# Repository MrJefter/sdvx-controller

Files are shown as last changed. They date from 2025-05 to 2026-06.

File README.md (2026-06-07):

# DIY SDVX Controller

[Read this page in Russian (Читать на русском)](README_RU.md)

SDVX Controller Assembly Render

Hello! This is a DIY controller project for Sound Voltex and similar rhythm games. It's built using an STM32 microcontroller (Black Pill), with custom firmware, a custom PCB, and a 3D-printed enclosure.

## Project Features

*   **Microcontroller** STM32F401 (on a Black Pill v3.0 board).
*   **Buttons** 7 main (BT-A, B, C, D, START) + 2 FX buttons (FX-L, FX-R) on CherryMX switches (e.g., Outemu Red).
*   **Rotary encoders** 2 x LPD3806 (VOL-L, VOL-R).
*   **Addressable RGB lighting** on WS2812B LEDs (optional, strip connected to PB0).
*   **Interface** USB HID (the controller is recognized as a standard game device).
*   **Fully 3D-printed enclosure**.
*   **PCB** ideal for single-layer home etching, no need to order a board.

## Demonstration

MVP Link

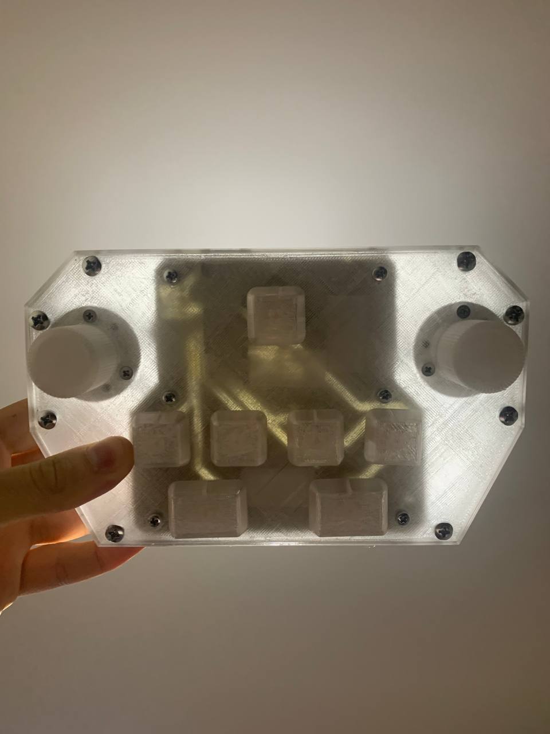
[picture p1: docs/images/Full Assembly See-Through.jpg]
Full Assembly See-Through


## Hardware

All hardware-related files are located in the [`hardware/`](./hardware/) folder.

### PCB

The PCB project was designed in EasyEDA. Source files, Gerber files for ordering, and the BOM are located in `hardware/pcb/`.

| Schematic | Board Layout |
|---|---|
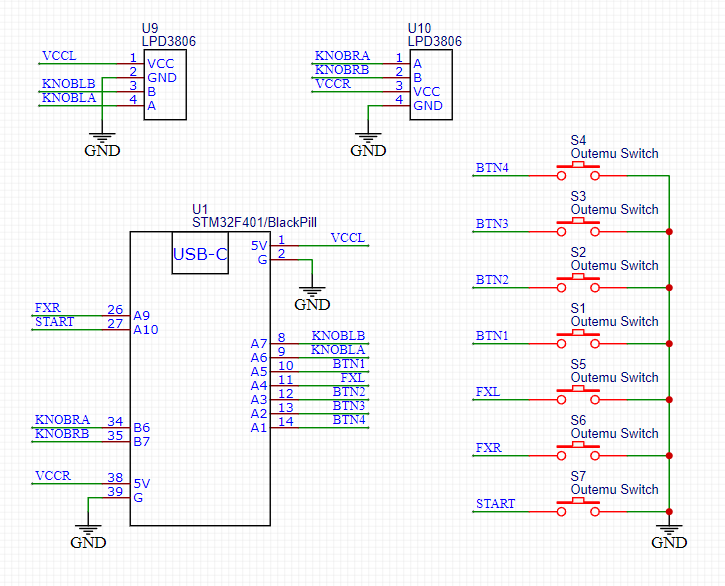
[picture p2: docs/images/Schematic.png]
Schematic
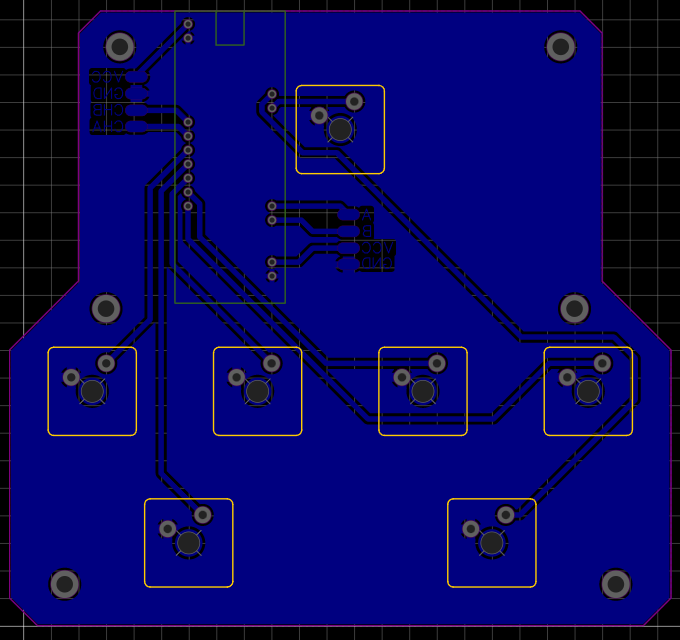
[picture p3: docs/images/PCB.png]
PCB Layout
|  |  |

**PCB Assembly Photos:**

| PCB Front | PCB Back |
|---|---|
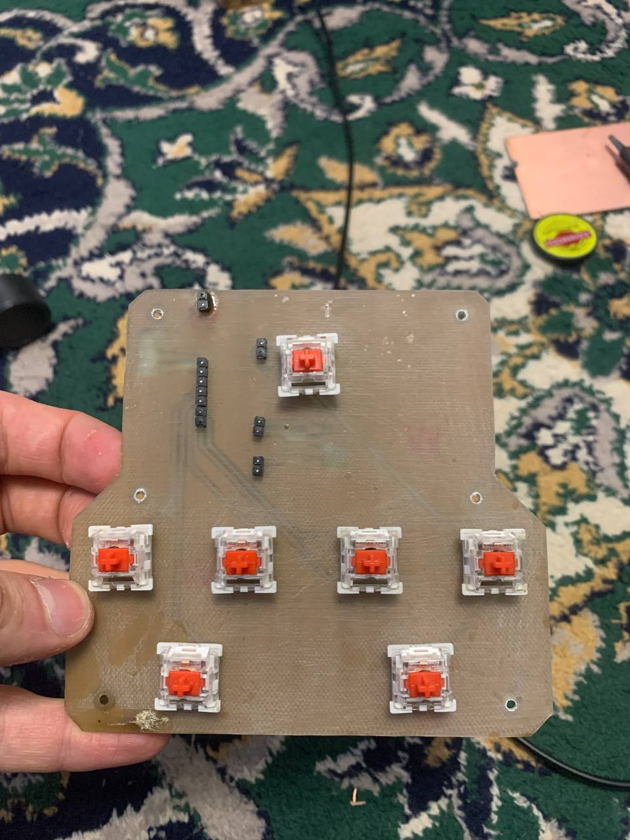
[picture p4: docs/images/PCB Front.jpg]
PCB Front
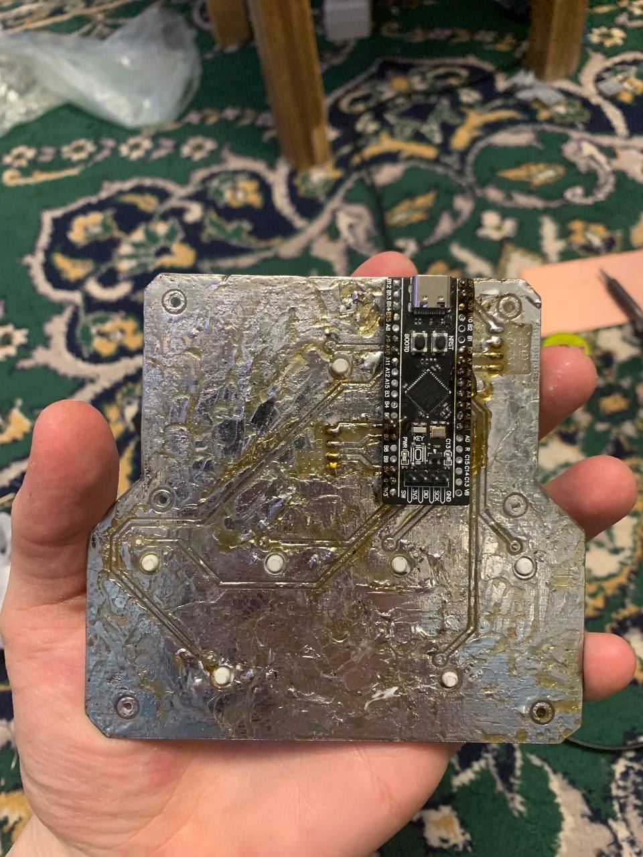
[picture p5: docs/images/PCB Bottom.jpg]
PCB Back
|  |  |

### Enclosure

3D models for the enclosure and its components were designed in KOMPAS-3D. Source CAD files, exported STEP files, and STL files for printing are located in `hardware/enclosure/` and `hardware/stl_for_printing/`.

3D models of the components used (BlackPill, encoders, switches) are in `hardware/enclosure/component_models_3d/`.

### Assembly Process (Photos)

| Connecting encoders to the front panel | LED strip installation |
|---|---|
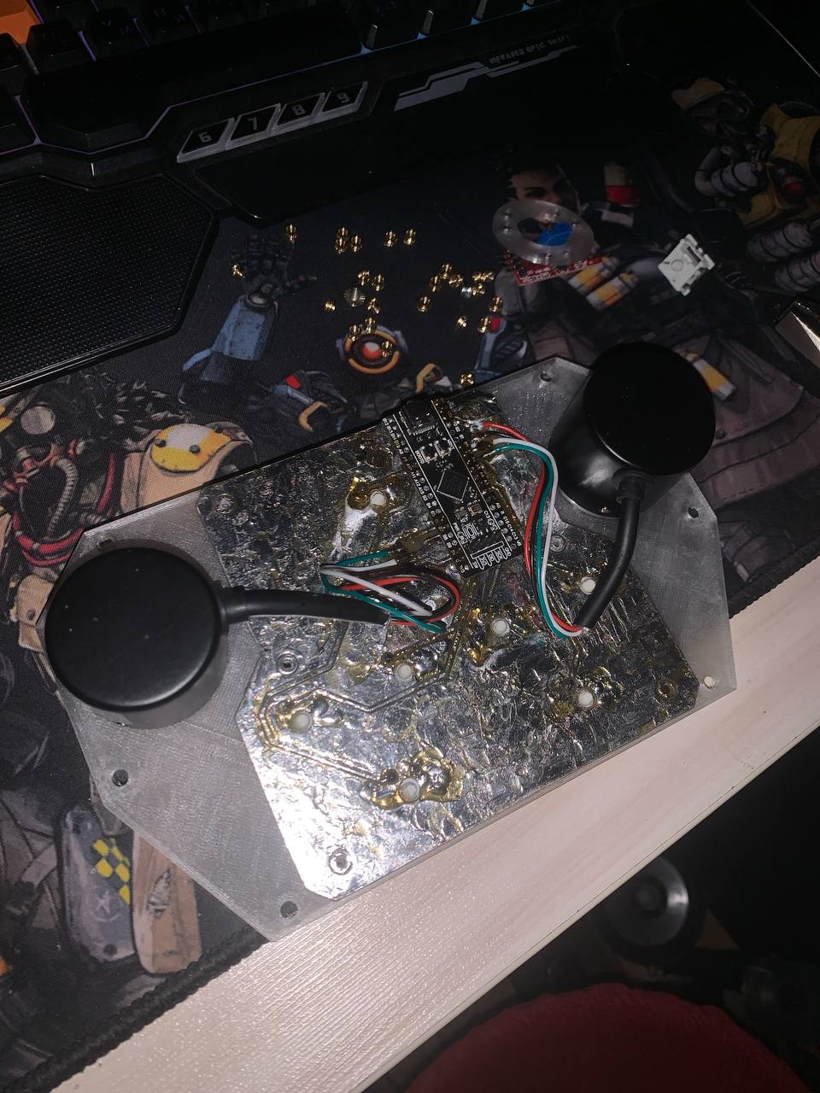
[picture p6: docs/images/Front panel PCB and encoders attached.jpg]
Front panel PCB and encoders attached
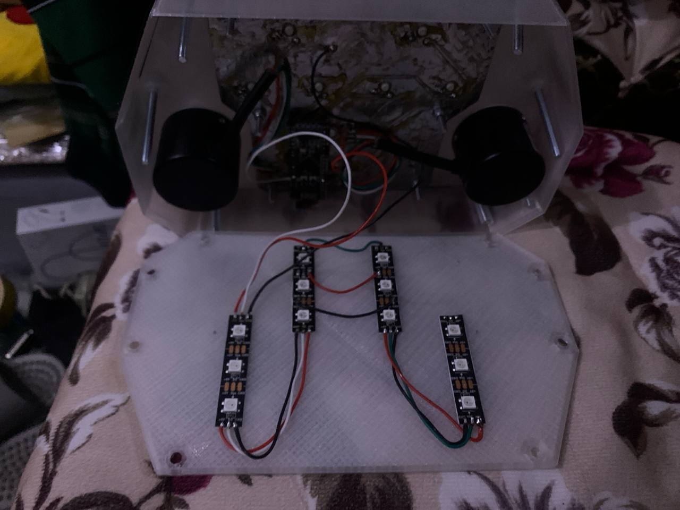
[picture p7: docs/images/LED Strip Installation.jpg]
LED Strip Installation
|  |  |

**BlackPill Modification:**

Optionally, a small hardware modification can be made to the BlackPill by adding a 150nF ceramic capacitor (as shown in the illustration). This allows entering DFU mode by holding the START button for 10 seconds.

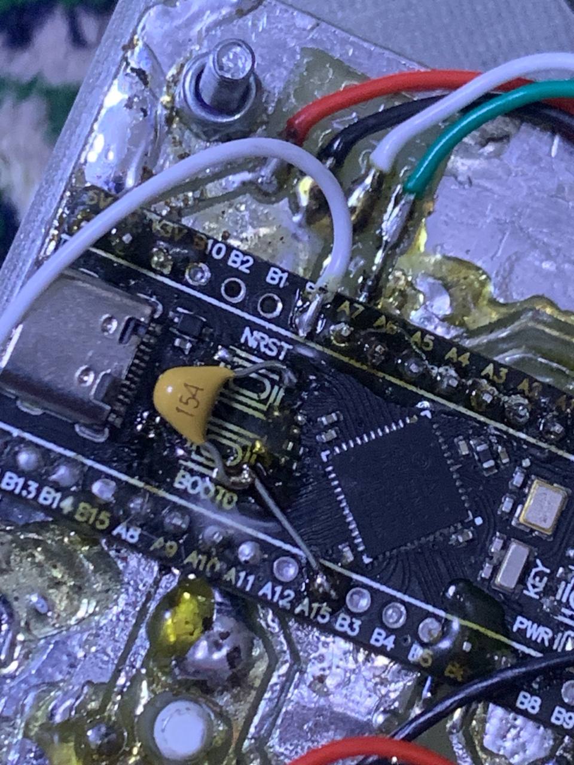
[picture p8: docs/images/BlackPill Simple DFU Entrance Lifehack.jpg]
BlackPill DFU Lifehack


## Software (Firmware)

The firmware for the STM32 microcontroller was developed using STM32CubeIDE. The source code is located in the [`firmware/`](./firmware/) folder.

Key firmware functions:
*   Polling buttons and encoders states.
*   Controlling RGB lighting, including visual effects.
*   Transmitting data to the PC via USB HID protocol.

## Assembly and Setup

[A DETAILED ASSEMBLY GUIDE, COMPONENT LIST, FIRMWARE FLASHING INSTRUCTIONS, AND SETUP DETAILS WILL BE HERE]

General steps:
1.  **Print the enclosure parts** using the STL files from the `hardware/stl_for_printing/` folder.
2.  **Manufacture the PCB:** Either order it using the Gerber files from `hardware/pcb/gerbers/` or **etch it yourself** using the project files from `hardware/pcb/easyeda_project/`.
3.  **Assemble the PCB**, solder buttons, encoders, LED strips.
4.  **Assemble the enclosure.**
5.  **Flash the microcontroller** - compile the project from `firmware/` (or use a pre-compiled binary from the releases) and flash the Black Pill (e.g., via DFU mode or using an ST-Link).
6.  **You're awesome!**

More detailed instructions for assembly and setup will be added to the `docs/` folder later (sometime).

## License

This project is licensed under the **GNU General Public License v3.0 (GPL-3.0)**. See [LICENSE](LICENSE) for details.

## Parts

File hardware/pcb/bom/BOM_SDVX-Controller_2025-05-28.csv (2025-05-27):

ID | Name | Designator | Quantity
1 | Outemu Switch | S1,S2,S3,S4,S5,S6,S7 | 7
2 | STM32F401/BlackPill | U1 | 1
3 | LPD3806 | U9,U10 | 2

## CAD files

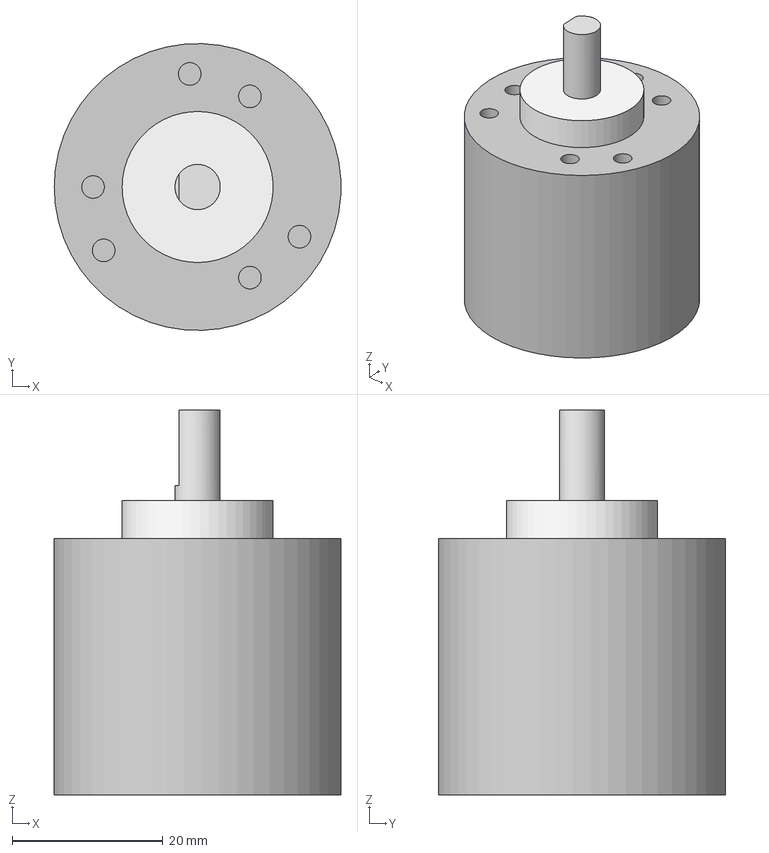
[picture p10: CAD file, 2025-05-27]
hardware/enclosure/component_models_3d/LPD3806/LPD3806.stp
38.0 x 38.0 x 51.0 mm

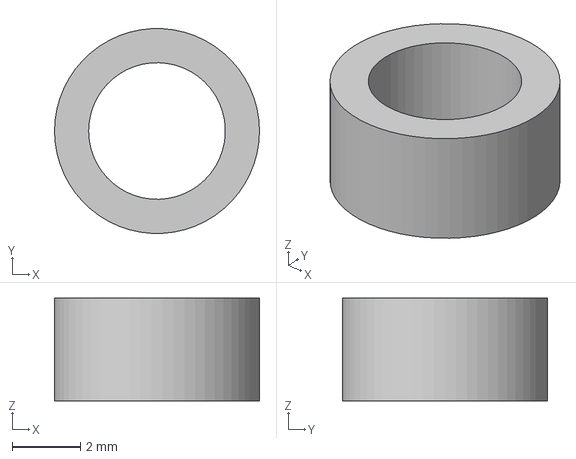
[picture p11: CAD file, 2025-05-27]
hardware/enclosure/export_step/SDVX Controller - Spacer 2.stp
6.00 x 5.99 x 3.00 mm

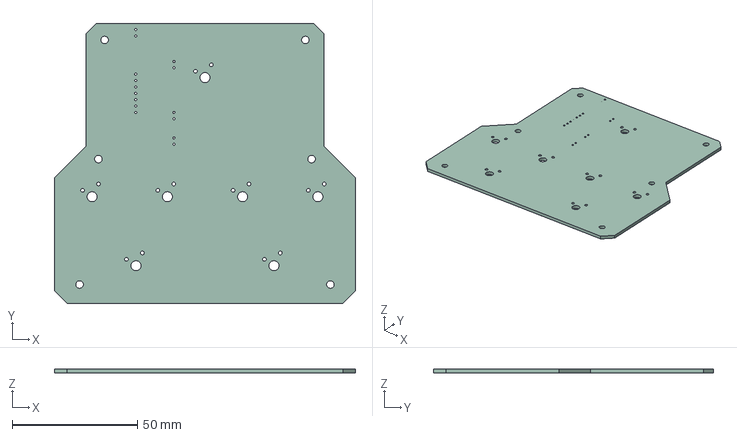
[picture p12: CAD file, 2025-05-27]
hardware/pcb/3d_model_for_assembly/SDVX Controller - PCB.step
120.0 x 111.5 x 1.60 mm

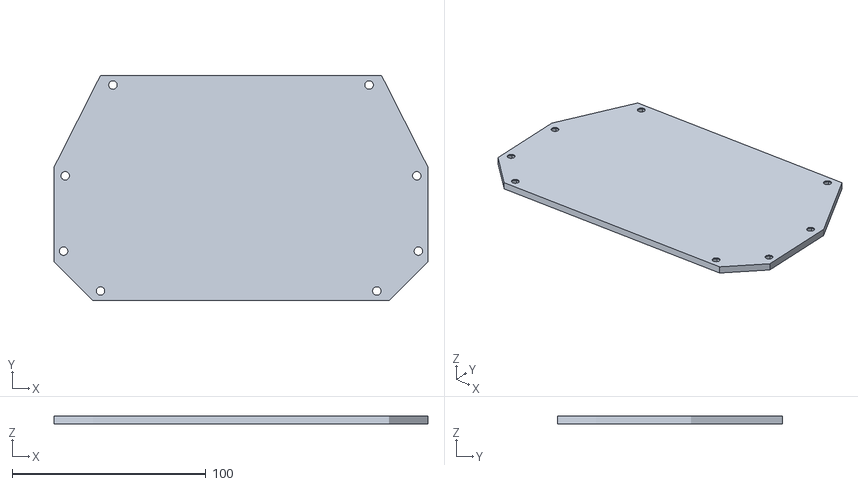
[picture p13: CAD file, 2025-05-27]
hardware/stl_for_printing/SDVX Controller - Bottom.stl
193.0 x 116.3 x 4.00

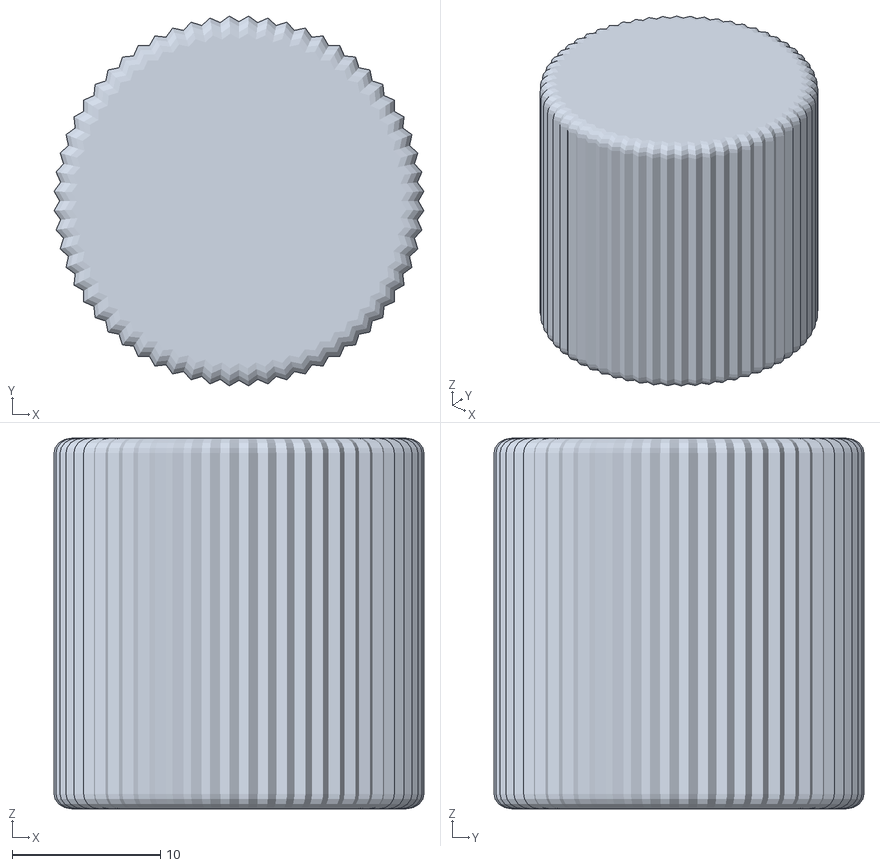
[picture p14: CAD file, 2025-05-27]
hardware/stl_for_printing/SDVX Controller - Knob.stl
25.0 x 25.0 x 25.0

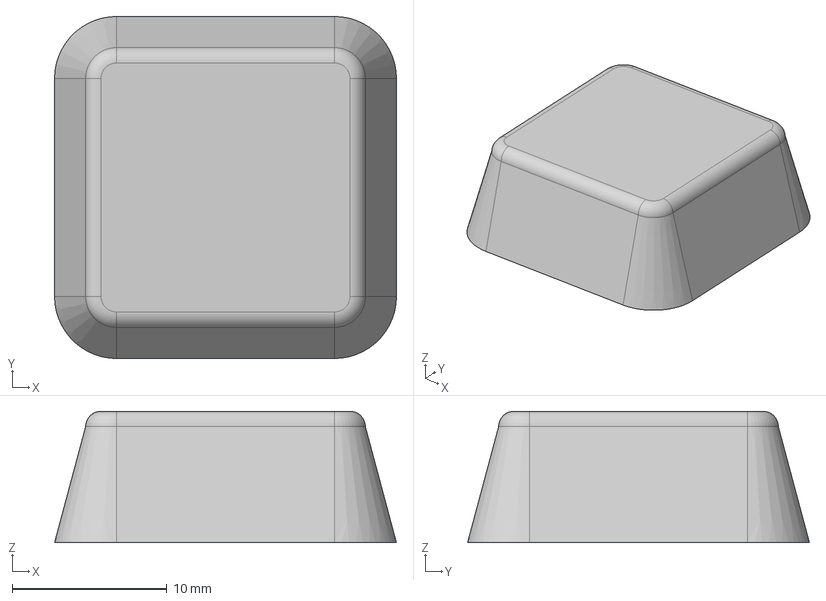
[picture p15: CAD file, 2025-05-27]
hardware/enclosure/export_step/SDVX Controller - Keycap (ABCD and Start).stp
22.1 x 22.1 x 8.50 mm

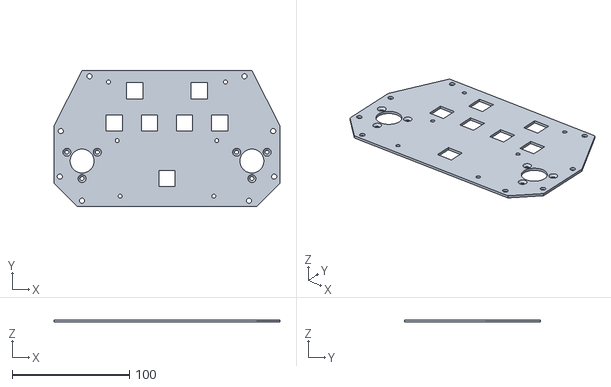
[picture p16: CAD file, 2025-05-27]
hardware/stl_for_printing/SDVX Controller - Front.stl
193.0 x 116.3 x 2.00

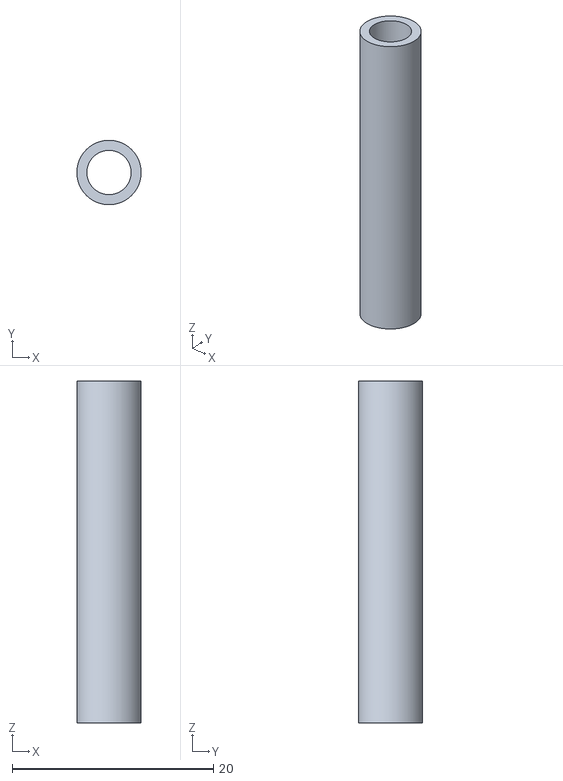
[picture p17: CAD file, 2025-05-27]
hardware/stl_for_printing/SDVX Controller - Spacer.stl
6.40 x 6.40 x 34.0

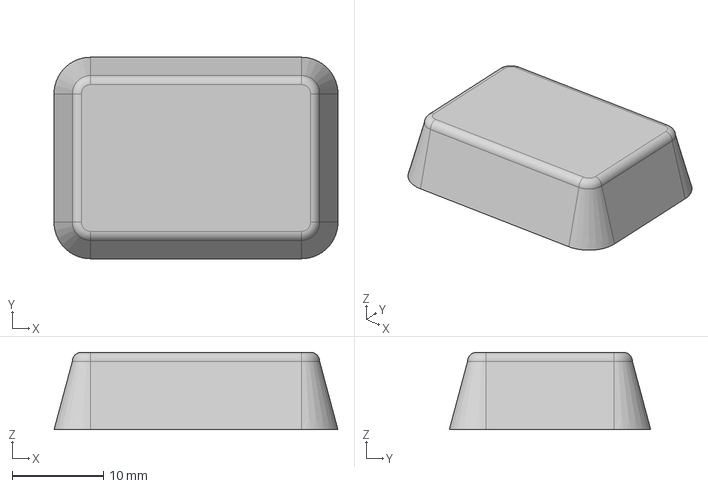
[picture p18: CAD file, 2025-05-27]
hardware/enclosure/export_step/SDVX Controller - Keycap (FX).stp
31.2 x 22.1 x 8.50 mm

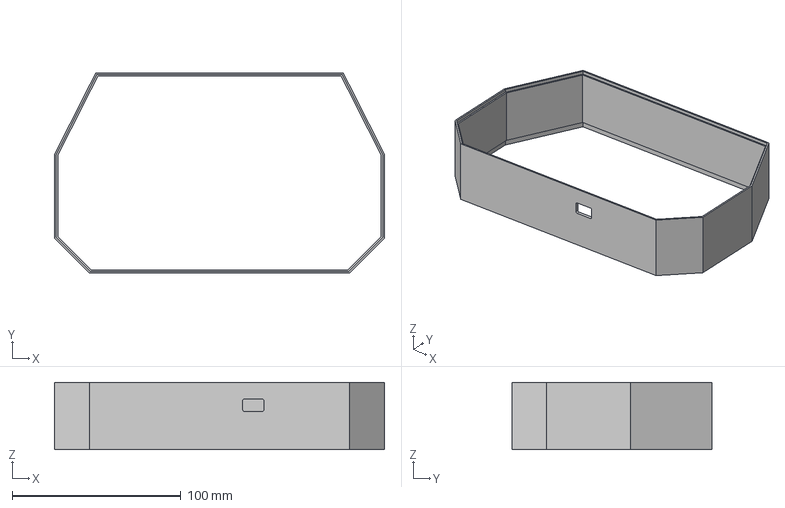
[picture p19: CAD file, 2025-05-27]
hardware/enclosure/export_step/SDVX Controller - Walls (middle).stp
195.4 x 118.7 x 39.8 mm

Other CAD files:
hardware/enclosure/export_step/SDVX Controller - Bottom.stp
hardware/enclosure/export_step/SDVX Controller - Front.stp
hardware/enclosure/export_step/SDVX Controller - Spacer.stp
hardware/stl_for_printing/SDVX Controller - Keycap (ABCD and Start).stl
hardware/stl_for_printing/SDVX Controller - Spacer 2.stl
hardware/stl_for_printing/SDVX Controller - Keycap (FX).stl
hardware/enclosure/export_step/SDVX Controller - Knob.stp
hardware/stl_for_printing/SDVX Controller - Walls (middle).stl

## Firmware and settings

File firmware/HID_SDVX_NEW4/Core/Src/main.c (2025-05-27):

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
/* Includes ------------------------------------------------------------------*/
#include "main.h"
#include "usb_device.h"

/* USER CODE BEGIN Includes */
#include "usbd_customhid.h"
#include <string.h>
#include <math.h>
#include "visEffect.h"
/* USER CODE END Includes */

/* USER CODE BEGIN PTD */

typedef struct {
	const GPIO_TypeDef* port;
	const uint16_t pin;
} Button_TypeDef;
/* USER CODE END PTD */

/* USER CODE BEGIN PD */
#define	JOYSTICK_REPORT_SIZE	5
#define	ENCODER_TIMER_PERIOD	0xFFFF // 65535

#define NUM_BUTTONS				7
#define DEBOUNCE_LOCKOUT_MS		3
#define MAIN_LOOP_DELAY_MS		1

#define ENCODER_SMOOTHING_ALPHA 0.15f

#define DFU_BUTTON_INDEX		6
#define DFU_HOLD_TIME_MS		5000
#define BOOT0_PORT				GPIOA
#define BOOT0_PIN				GPIO_PIN_15
/* USER CODE END PD */

TIM_HandleTypeDef htim3;
TIM_HandleTypeDef htim4;

/* USER CODE BEGIN PV */
extern USBD_HandleTypeDef hUsbDeviceFS;

USBD_JoystickReport_TypeDef joystickReport;

volatile int16_t g_encoder_delta_x = 0;
volatile int16_t g_encoder_delta_y = 0;

static uint16_t last_encoder1_count = 0;
static uint16_t last_encoder2_count = 0;
static int32_t current_axis_x_raw = 0;
static int32_t current_axis_y_raw = 0;

// Make button definitions const
const Button_TypeDef buttons[NUM_BUTTONS] = {
		{GPIOA, BTN1_Pin},
		{GPIOA, BTN2_Pin},
		{GPIOA, BTN3_Pin},
		{GPIOA, BTN4_Pin},
		{GPIOA, FXL_Pin},
		{GPIOA, FXR_Pin},
		{GPIOA, START_Pin}
};

// These are modified by EXTI callback, hence volatile
volatile uint8_t button_stable_state[NUM_BUTTONS] = {0};
volatile uint32_t button_lockout_timer[NUM_BUTTONS] = {0};

static float smoothed_axis_x = 0.0f;
static float smoothed_axis_y = 0.0f;

// These are modified by EXTI callback, hence volatile
static volatile uint32_t dfu_button_press_time = 0;
static volatile uint8_t dfu_button_currently_pressed = 0;
/* USER CODE END PV */

void SystemClock_Config(void);
static void MX_GPIO_Init(void);
static void MX_TIM3_Init(void);
static void MX_TIM4_Init(void);
/* USER CODE BEGIN PFP */
static void GoToBootloader(void);
static void Read_Encoders(void);
static void Send_HID_Report(void);
static void Process_Buttons(void);
static void Check_DFU_Entry(void);
/* USER CODE END PFP */

/**
  * @brief  The application entry point.
  * @retval int
  */
int main(void)
{

  /* MCU Configuration--------------------------------------------------------*/

  /* Reset of all peripherals, Initializes the Flash interface and the Systick. */
  HAL_Init();

  /* Configure the system clock */
  SystemClock_Config();

  /* Initialize all configured peripherals */
  MX_GPIO_Init();
  MX_TIM3_Init();
  MX_TIM4_Init();
  MX_USB_DEVICE_Init();
  /* USER CODE BEGIN 2 */

  visInit();

  if (HAL_TIM_Encoder_Start(&htim3, TIM_CHANNEL_ALL) != HAL_OK) {
    Error_Handler();
  }
  if (HAL_TIM_Encoder_Start(&htim4, TIM_CHANNEL_ALL) != HAL_OK) {
    Error_Handler();
  }

  // Use defined constant for clarity if desired, though 0xFFFF is common
  __HAL_TIM_SET_COUNTER(&htim3, 0);
  __HAL_TIM_SET_COUNTER(&htim4, 0);

  // Read initial counter values *after* setting them
  last_encoder1_count = __HAL_TIM_GET_COUNTER(&htim3);
  last_encoder2_count = __HAL_TIM_GET_COUNTER(&htim4);
  current_axis_x_raw = 0;
  current_axis_y_raw = 0;

  // Initialize report struct
  memset(&joystickReport, 0, sizeof(joystickReport));
  // Redundant if memset is used, but explicit:
  // joystickReport.axis_x = 0;
  // joystickReport.axis_y = 0;
  // joystickReport.buttons = 0;

  // memset(button_stable_state, 0, sizeof(button_stable_state)); // Already initialized statically
  // memset(button_lockout_timer, 0, sizeof(button_lockout_timer)); // Already initialized statically
  /* USER CODE END 2 */

  /* Infinite loop */
  /* USER CODE BEGIN WHILE */
  while (1)
  {
    /* USER CODE END WHILE */

    /* USER CODE BEGIN 3 */
	visHandle();
	Read_Encoders();
	Process_Buttons();
	Check_DFU_Entry();
	Send_HID_Report();

	// Consider if HAL_Delay is strictly necessary or if timing can be handled differently
	// For simple loop rate control, it's acceptable.
	HAL_Delay(MAIN_LOOP_DELAY_MS);
  }
  /* USER CODE END 3 */
}

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
/* USER CODE BEGIN 4 */

/**
  * @brief Process stable button states into HID report format.
  * @retval None
  */
static void Process_Buttons(void)
{
	uint8_t final_button_state = 0;
	// This loop assumes button_stable_state[i] is always 0 or 1.
	for (int i = 0; i < NUM_BUTTONS; i++) {
		final_button_state |= (button_stable_state[i] << i);
	}
	joystickReport.buttons = final_button_state;
}

/**
  * @brief Check if DFU button is held long enough to enter bootloader.
  * @retval None
  */
static void Check_DFU_Entry(void)
{
    // Read volatile variables once
	uint32_t press_time = dfu_button_press_time;
	uint8_t is_pressed = dfu_button_currently_pressed;

	// Check only if the button is currently considered pressed and a start time is logged
	if (is_pressed && press_time != 0) {
		if ((HAL_GetTick() - press_time) >= DFU_HOLD_TIME_MS) {
			GoToBootloader(); // This function does not return
		}
	}
}

/**
 * @brief EXTI Line Detection Callback. Handles button debouncing.
 * @param GPIO_Pin: Specifies the port pin connected to corresponding EXTI line.
 * @retval None
 */
void HAL_GPIO_EXTI_Callback(uint16_t GPIO_Pin) {
	uint32_t current_tick = HAL_GetTick();

	// Find which button triggered the interrupt
	for (int i = 0; i < NUM_BUTTONS; i++) {
		if (GPIO_Pin == buttons[i].pin) {
			// Check if lockout period has expired
			if (current_tick >= button_lockout_timer[i]) {
				// Read the *current* raw state (interrupt might be delayed slightly)
                // Assumes PULLUP resistor and button connects to GND when pressed
				uint8_t current_raw_state = (HAL_GPIO_ReadPin(buttons[i].port, buttons[i].pin) == GPIO_PIN_RESET);

                // Check if the stable state needs updating
				if (current_raw_state != button_stable_state[i]) {
					button_stable_state[i] = current_raw_state;
					// Start new lockout period
					button_lockout_timer[i] = current_tick + DEBOUNCE_LOCKOUT_MS;

					// Specific logic for the DFU button
					if (i == DFU_BUTTON_INDEX) {
						if (current_raw_state == 1) { // Button pressed
                            // Only record press time if it wasn't already considered pressed
                            // Protect against HAL_GetTick() potentially returning 0 initially
							if (dfu_button_press_time == 0) {
								dfu_button_press_time = current_tick ? current_tick : 1;
							}
							dfu_button_currently_pressed = 1;
						} else { // Button released
							dfu_button_press_time = 0; // Reset timer
							dfu_button_currently_pressed = 0;
						}
					}
				}
			}
			// Found the button, no need to check others
			break;
		}
	}
}

/**
  * @brief Set BOOT0 pin and trigger system reset to enter DFU bootloader.
  * @retval None. This function does not return.
  */
static void GoToBootloader(void) {
	HAL_GPIO_WritePin(BOOT0_PORT, BOOT0_PIN, GPIO_PIN_SET);
	HAL_Delay(250); // Short delay to ensure pin state is stable
	NVIC_SystemReset(); // Trigger reset
}

/**
  * @brief Read encoder values, calculate deltas, apply smoothing, and update report.
  * @retval None
  */
static void Read_Encoders(void)
{
    // Read hardware counters
	uint16_t current_encoder1_count = __HAL_TIM_GET_COUNTER(&htim3);
	uint16_t current_encoder2_count = __HAL_TIM_GET_COUNTER(&htim4);

    // Calculate delta using signed 16-bit arithmetic to handle wrap-around correctly
	int16_t delta1 = (int16_t)(current_encoder1_count - last_encoder1_count);
	int16_t delta2 = (int16_t)(current_encoder2_count - last_encoder2_count);

    // Store current counts for next iteration
	last_encoder1_count = current_encoder1_count;
	last_encoder2_count = current_encoder2_count;

    // Update global delta values (used by visEffect)
	g_encoder_delta_x = delta1;
	g_encoder_delta_y = delta2;

    // Accumulate raw encoder values
	current_axis_x_raw += delta1;
	current_axis_y_raw += delta2;

    // Apply exponential moving average (EMA) smoothing
	smoothed_axis_x = (ENCODER_SMOOTHING_ALPHA * (float)current_axis_x_raw) + ((1.0f - ENCODER_SMOOTHING_ALPHA) * smoothed_axis_x);
	smoothed_axis_y = (ENCODER_SMOOTHING_ALPHA * (float)current_axis_y_raw) + ((1.0f - ENCODER_SMOOTHING_ALPHA) * smoothed_axis_y);

    // Scale and round the smoothed value for the report
    // Adjust scaling factor (10.0f) as needed for desired sensitivity/range
	int32_t scaled_x = (int32_t)roundf(smoothed_axis_x / 10.0f);
	int32_t scaled_y = (int32_t)roundf(smoothed_axis_y / 10.0f);

    // Clamp scaled values to the report's axis range (uint16_t: 0-65535)
	joystickReport.axis_x = (uint16_t)scaled_x;
	joystickReport.axis_y = (uint16_t)scaled_y;
}


/**
  * @brief Send the current joystick HID report over USB.
  * @retval None
  */
static void Send_HID_Report(void)
{
    // Only send if USB device is configured and ready
	if (hUsbDeviceFS.dev_state == USBD_STATE_CONFIGURED) {
		USBD_CUSTOM_HID_SendReport(&hUsbDeviceFS, (uint8_t*)&joystickReport, JOYSTICK_REPORT_SIZE);
	}
}

/* USER CODE END 4 */
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


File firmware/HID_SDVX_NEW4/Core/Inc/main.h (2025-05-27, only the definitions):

#define BTN4_Pin GPIO_PIN_1
#define BTN4_GPIO_Port GPIOA
#define BTN4_EXTI_IRQn EXTI1_IRQn
#define BTN3_Pin GPIO_PIN_2
#define BTN3_GPIO_Port GPIOA
#define BTN3_EXTI_IRQn EXTI2_IRQn
#define BTN2_Pin GPIO_PIN_3
#define BTN2_GPIO_Port GPIOA
#define BTN2_EXTI_IRQn EXTI3_IRQn
#define FXL_Pin GPIO_PIN_4
#define FXL_GPIO_Port GPIOA
#define FXL_EXTI_IRQn EXTI4_IRQn
#define BTN1_Pin GPIO_PIN_5
#define BTN1_GPIO_Port GPIOA
#define BTN1_EXTI_IRQn EXTI9_5_IRQn
#define KNOBLA_Pin GPIO_PIN_6
#define KNOBLA_GPIO_Port GPIOA
#define KNOBLB_Pin GPIO_PIN_7
#define KNOBLB_GPIO_Port GPIOA
#define FXR_Pin GPIO_PIN_9
#define FXR_GPIO_Port GPIOA
#define FXR_EXTI_IRQn EXTI9_5_IRQn
#define START_Pin GPIO_PIN_10
#define START_GPIO_Port GPIOA
#define START_EXTI_IRQn EXTI15_10_IRQn
#define KNOBRA_Pin GPIO_PIN_6
#define KNOBRA_GPIO_Port GPIOB
#define KNOBRB_Pin GPIO_PIN_7
#define KNOBRB_GPIO_Port GPIOB

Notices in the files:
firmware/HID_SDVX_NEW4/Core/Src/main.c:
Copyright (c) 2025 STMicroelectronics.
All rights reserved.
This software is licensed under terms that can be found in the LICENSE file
